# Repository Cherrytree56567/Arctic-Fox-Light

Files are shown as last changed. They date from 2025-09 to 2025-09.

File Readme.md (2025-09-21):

# Minecraft Arctic Fox Lamp
A simple Minecraft Themed Arctic Fox Lamp that features an ESP32 C6 Mini with ESP Matter Support which supports Temperature, Hue/Sat and Brightness.

## Features
 - Custom Color LED
 - Smart Home Integration
 - Matter Support
 - Enclosure

## Build
To Run the Matter ESP32 Program, install `ESP-IDF`:
```
git clone --recursive https://github.com/espressif/esp-idf.git
cd esp-idf
git submodule update --init --recursive
./install.sh
cd ../
```
Install `ESP-Matter`:
```
git clone https://github.com/espressif/esp-matter.git
cd esp-matter
git submodule update
cd connectedhomeip/connedtedhomeip/
git submodule update
cd ../../
```
Next source both repo's:
```
cd esp-idf
source ./export.sh
cd ../
cd esp-matter
source ./export.sh
cd ../
```

Then build the project by running
```
idf.py build
```

## Running
To run the application, run:
```
idf.py flash
```

## Credits
 - [Template ESP32 Matter Repo](https://github.com/oidebrett/starter-esp-matter-app)

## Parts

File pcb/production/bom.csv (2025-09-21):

Designator | Footprint | Quantity | Value | LCSC Part #
C1, C13 | 0805 | 2 | 10uF | C15850
C12 | 0805 | 1 | 100nF | C49678
D1 | LED_WS2812B_PLCC4_5.0x5.0mm_P3.2mm | 1 | WS2812B
J1 | USB_C_Receptacle_HCTL_HC-TYPE-C-16P-01A | 1 | USB_C_Receptacle_USB2.0_16P
R1, R2 | 0201 | 2 | R5.1K
R10, R8, R9 | 0201 | 3 | R10k
R3, R6 | 0201 | 2 | R27O
R7 | 0201 | 1 | R330o
U1 | TO-263-5_TabPin3 | 1 | LM2596S-5
U2 | ESP32-C6-MINI-1 | 1 | ESP32-C6-MINI-1/U
U3 | TO-263-5_TabPin3 | 1 | LM2596S-3.3
U4 | DIP794W45P254L1930H508Q14 | 1 | SN74AHCT125N

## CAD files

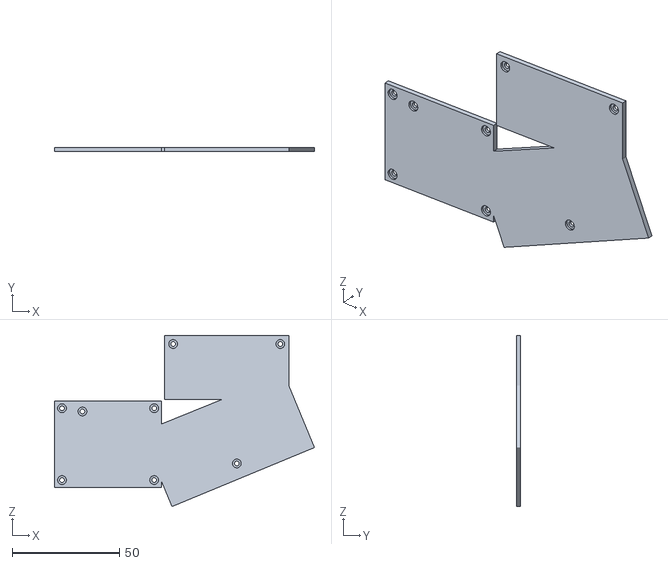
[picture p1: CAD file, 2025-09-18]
enclosure/Part Studio 1 - Part 1.stl
121.3 x 2.00 x 79.9

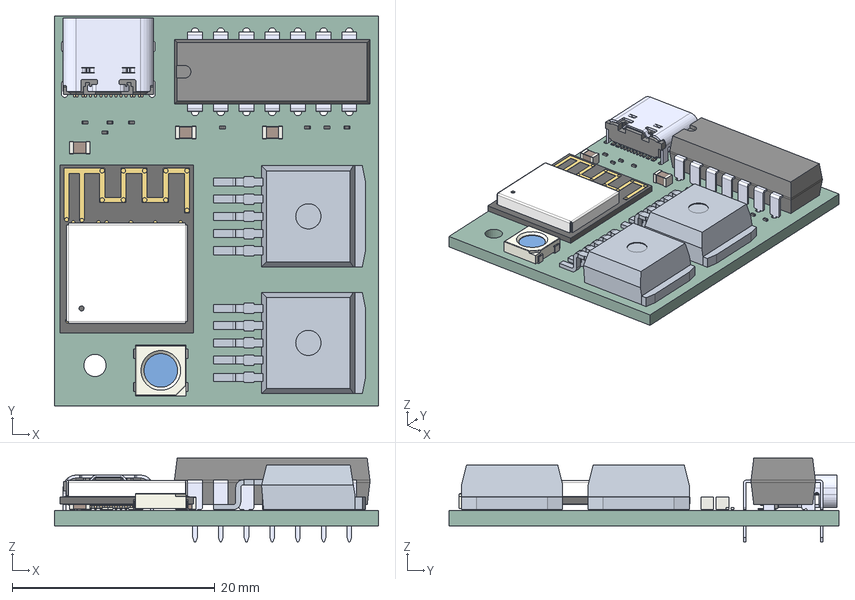
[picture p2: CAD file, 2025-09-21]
pcb/arcticfoxlight.step
32.0 x 38.5 x 8.26 mm
R_0201_0603Metric x 8
SN74AHCT125N
LED_WS2812B_PLCC4_5.0x5.0mm_P3.2mm
KH-TYPE-C-16P--3DModel-STEP-269445
DFN1006.STEP^DFN1006.STEP_Submodel-SOD882_part_DesignRootModel_PCB_ ESP32-C3-MINI-1_V1(2)_PCB_ESP32-C3-MINI-1_V1
R0201_20210301.STEP^R0201_20210301.STEP_Submodel-R0201_part_ DesignRootModel_PCB_ESP32-C3-MINI-1_V1(2)_PCB_ESP32-C3-MINI-1_V1 x 3
placementOutline^Submodel-noModelForPart_MINI-ANT-TYPED-H_1968823293_ Submodel-MINI-ANT-TYPED-H_1968823293_part_DesignRootModel_PCB_ ESP32-C3-MINI-1_V1(2)_PCB_E
placementOutline-0^Submodel-noModelForPart_MINI-ANT-TYPED-H_1968823293_ Submodel-MINI-ANT-TYPED-H_1968823293_part_DesignRootModel_PCB_ ESP32-C3-MINI-1_V1(2)_PCB
placementOutline-1^Submodel-noModelForPart_MINI-ANT-TYPED-H_1968823293_ Submodel-MINI-ANT-TYPED-H_1968823293_part_DesignRootModel_PCB_ ESP32-C3-MINI-1_V1(2)_PCB
placementOutline-2^Submodel-noModelForPart_MINI-ANT-TYPED-H_1968823293_ Submodel-MINI-ANT-TYPED-H_1968823293_part_DesignRootModel_PCB_ ESP32-C3-MINI-1_V1(2)_PCB
placementOutline-3^Submodel-noModelForPart_MINI-ANT-TYPED-H_1968823293_ Submodel-MINI-ANT-TYPED-H_1968823293_part_DesignRootModel_PCB_ ESP32-C3-MINI-1_V1(2)_PCB
placementOutline-4^Submodel-noModelForPart_MINI-ANT-TYPED-H_1968823293_ Submodel-MINI-ANT-TYPED-H_1968823293_part_DesignRootModel_PCB_ ESP32-C3-MINI-1_V1(2)_PCB
placementOutline-5^Submodel-noModelForPart_MINI-ANT-TYPED-H_1968823293_ Submodel-MINI-ANT-TYPED-H_1968823293_part_DesignRootModel_PCB_ ESP32-C3-MINI-1_V1(2)_PCB
trace_4^Submodel-MINI-ANT-TYPED-H_1968823293_part_DesignRootModel_PCB_ ESP32-C3-MINI-1_V1(2)_PCB_ESP32-C3-MINI-1_V1
trace_1^Submodel-MINI-ANT-TYPED-H_1968823293_part_DesignRootModel_PCB_ ESP32-C3-MINI-1_V1(2)_PCB_ESP32-C3-MINI-1_V1
C0402_20210301.STEP^C0402_20210301.STEP_Submodel-C0402_part_ DesignRootModel_PCB_ESP32-C3-MINI-1_V1(2)_PCB_ESP32-C3-MINI-1_V1
C0201_20210301.STEP^C0201_20210301.STEP_Submodel-C0201_part_ DesignRootModel_PCB_ESP32-C3-MINI-1_V1(2)_PCB_ESP32-C3-MINI-1_V1 x 11
L0201_20210301.STEP^L0201_20210301.STEP_Submodel-L0201_part_ DesignRootModel_PCB_ESP32-C3-MINI-1_V1(2)_PCB_ESP32-C3-MINI-1_V1 x 2
XTAL3225_20210301.STEP^XTAL3225_20210301.STEP_Submodel-XTAL3225_part_ DesignRootModel_PCB_ESP32-C3-MINI-1_V1(2)_PCB_ESP32-C3-MINI-1_V1
ESP32-C3_20210301.STEP^ESP32-C3_20210301.STEP_Submodel-QFN32_0P5_5_ part_DesignRootModel_PCB_ESP32-C3-MINI-1_V1(2)_PCB_ESP32-C3-MINI-1_V1
uid__4^DesignRootModel_PCB_ESP32-C3-MINI-1_V1(2)_PCB_ESP32-C3-MINI-1_ V1
uid__4-22^DesignRootModel_PCB_ESP32-C3-MINI-1_V1(2)_PCB_ ESP32-C3-MINI-1_V1
uid__4-23^DesignRootModel_PCB_ESP32-C3-MINI-1_V1(2)_PCB_ ESP32-C3-MINI-1_V1
uid__4-24^DesignRootModel_PCB_ESP32-C3-MINI-1_V1(2)_PCB_ ESP32-C3-MINI-1_V1
uid__4-25^DesignRootModel_PCB_ESP32-C3-MINI-1_V1(2)_PCB_ ESP32-C3-MINI-1_V1
uid__4-26^DesignRootModel_PCB_ESP32-C3-MINI-1_V1(2)_PCB_ ESP32-C3-MINI-1_V1
uid__4-27^DesignRootModel_PCB_ESP32-C3-MINI-1_V1(2)_PCB_ ESP32-C3-MINI-1_V1
uid__4-28^DesignRootModel_PCB_ESP32-C3-MINI-1_V1(2)_PCB_ ESP32-C3-MINI-1_V1
uid__4-29^DesignRootModel_PCB_ESP32-C3-MINI-1_V1(2)_PCB_ ESP32-C3-MINI-1_V1
uid__4-30^DesignRootModel_PCB_ESP32-C3-MINI-1_V1(2)_PCB_ ESP32-C3-MINI-1_V1
uid__4-31^DesignRootModel_PCB_ESP32-C3-MINI-1_V1(2)_PCB_ ESP32-C3-MINI-1_V1
uid__4-32^DesignRootModel_PCB_ESP32-C3-MINI-1_V1(2)_PCB_ ESP32-C3-MINI-1_V1
uid__4-33^DesignRootModel_PCB_ESP32-C3-MINI-1_V1(2)_PCB_ ESP32-C3-MINI-1_V1
uid__4-34^DesignRootModel_PCB_ESP32-C3-MINI-1_V1(2)_PCB_ ESP32-C3-MINI-1_V1
uid__4-35^DesignRootModel_PCB_ESP32-C3-MINI-1_V1(2)_PCB_ ESP32-C3-MINI-1_V1
uid__4-36^DesignRootModel_PCB_ESP32-C3-MINI-1_V1(2)_PCB_ ESP32-C3-MINI-1_V1
uid__4-37^DesignRootModel_PCB_ESP32-C3-MINI-1_V1(2)_PCB_ ESP32-C3-MINI-1_V1
uid__4-38^DesignRootModel_PCB_ESP32-C3-MINI-1_V1(2)_PCB_ ESP32-C3-MINI-1_V1
uid__4-39^DesignRootModel_PCB_ESP32-C3-MINI-1_V1(2)_PCB_ ESP32-C3-MINI-1_V1
uid__4-40^DesignRootModel_PCB_ESP32-C3-MINI-1_V1(2)_PCB_ ESP32-C3-MINI-1_V1
uid__4-41^DesignRootModel_PCB_ESP32-C3-MINI-1_V1(2)_PCB_ ESP32-C3-MINI-1_V1
uid__4-42^DesignRootModel_PCB_ESP32-C3-MINI-1_V1(2)_PCB_ ESP32-C3-MINI-1_V1
uid__4-43^DesignRootModel_PCB_ESP32-C3-MINI-1_V1(2)_PCB_ ESP32-C3-MINI-1_V1
uid__4-44^DesignRootModel_PCB_ESP32-C3-MINI-1_V1(2)_PCB_ ESP32-C3-MINI-1_V1
uid__4-45^DesignRootModel_PCB_ESP32-C3-MINI-1_V1(2)_PCB_ ESP32-C3-MINI-1_V1
uid__4-46^DesignRootModel_PCB_ESP32-C3-MINI-1_V1(2)_PCB_ ESP32-C3-MINI-1_V1
uid__4-47^DesignRootModel_PCB_ESP32-C3-MINI-1_V1(2)_PCB_ ESP32-C3-MINI-1_V1
uid__4-48^DesignRootModel_PCB_ESP32-C3-MINI-1_V1(2)_PCB_ ESP32-C3-MINI-1_V1
uid__4-49^DesignRootModel_PCB_ESP32-C3-MINI-1_V1(2)_PCB_ ESP32-C3-MINI-1_V1
uid__4-50^DesignRootModel_PCB_ESP32-C3-MINI-1_V1(2)_PCB_ ESP32-C3-MINI-1_V1
uid__4-51^DesignRootModel_PCB_ESP32-C3-MINI-1_V1(2)_PCB_ ESP32-C3-MINI-1_V1
uid__4-52^DesignRootModel_PCB_ESP32-C3-MINI-1_V1(2)_PCB_ ESP32-C3-MINI-1_V1
uid__4-53^DesignRootModel_PCB_ESP32-C3-MINI-1_V1(2)_PCB_ ESP32-C3-MINI-1_V1
uid__4-54^DesignRootModel_PCB_ESP32-C3-MINI-1_V1(2)_PCB_ ESP32-C3-MINI-1_V1
uid__4-55^DesignRootModel_PCB_ESP32-C3-MINI-1_V1(2)_PCB_ ESP32-C3-MINI-1_V1
uid__4-56^DesignRootModel_PCB_ESP32-C3-MINI-1_V1(2)_PCB_ ESP32-C3-MINI-1_V1
uid__4-57^DesignRootModel_PCB_ESP32-C3-MINI-1_V1(2)_PCB_ ESP32-C3-MINI-1_V1
uid__4-58^DesignRootModel_PCB_ESP32-C3-MINI-1_V1(2)_PCB_ ESP32-C3-MINI-1_V1
uid__4-59^DesignRootModel_PCB_ESP32-C3-MINI-1_V1(2)_PCB_ ESP32-C3-MINI-1_V1
uid__4-60^DesignRootModel_PCB_ESP32-C3-MINI-1_V1(2)_PCB_ ESP32-C3-MINI-1_V1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

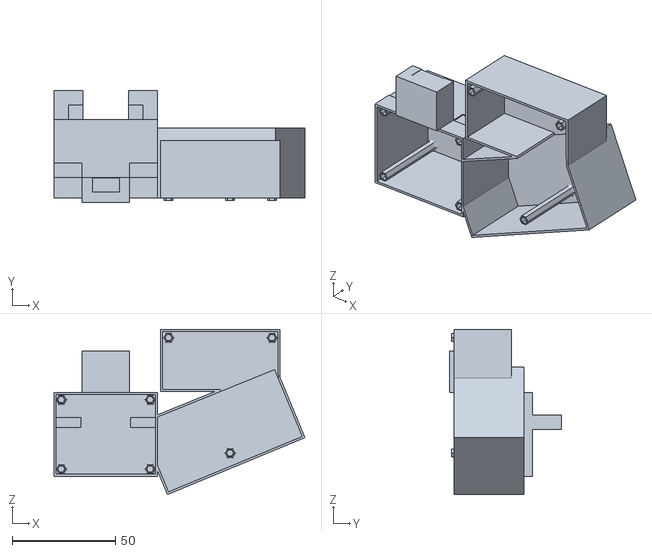
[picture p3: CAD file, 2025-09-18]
enclosure/Part Studio 1 - Part 2.stl
121.3 x 54.0 x 79.9

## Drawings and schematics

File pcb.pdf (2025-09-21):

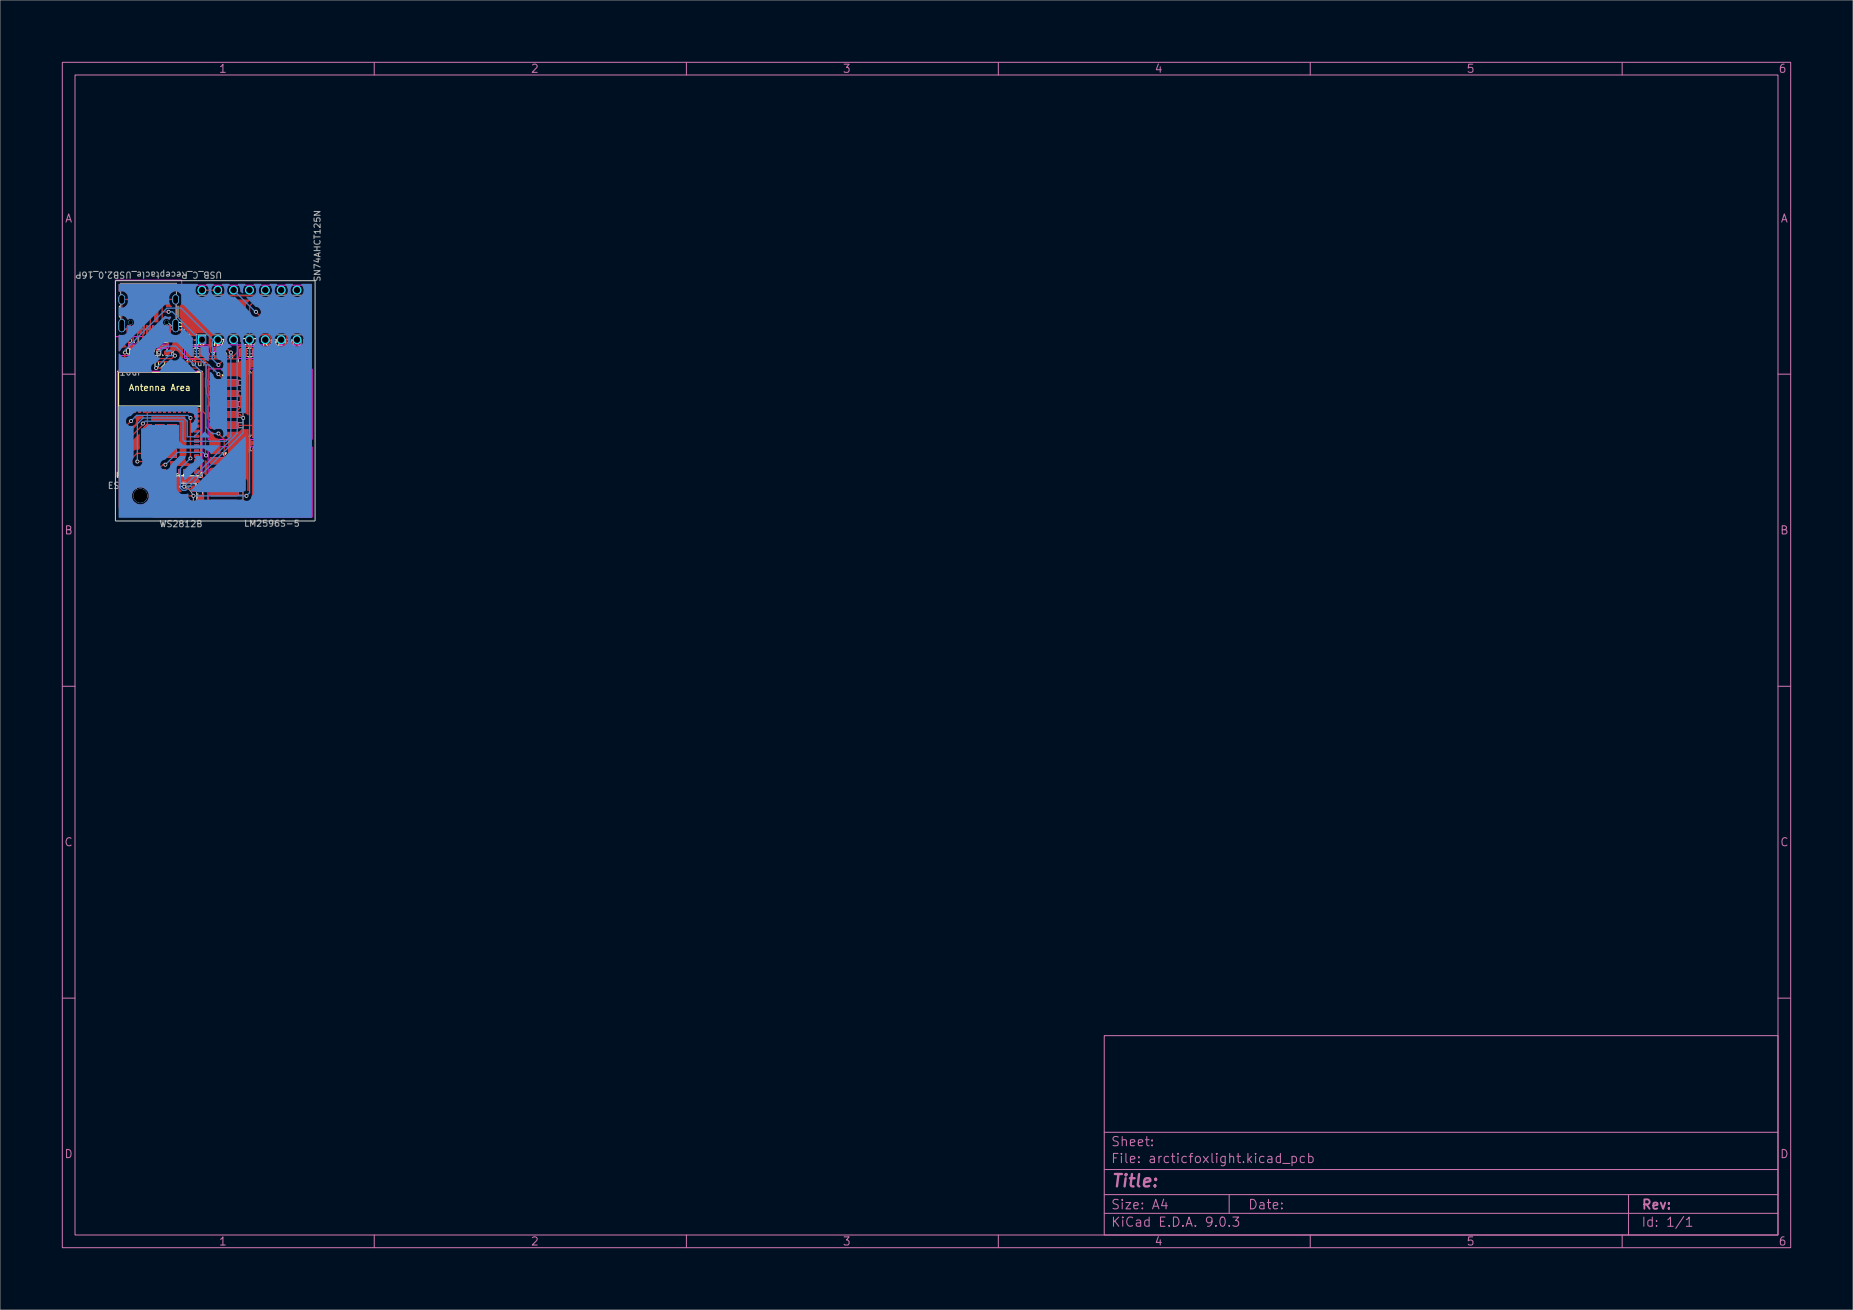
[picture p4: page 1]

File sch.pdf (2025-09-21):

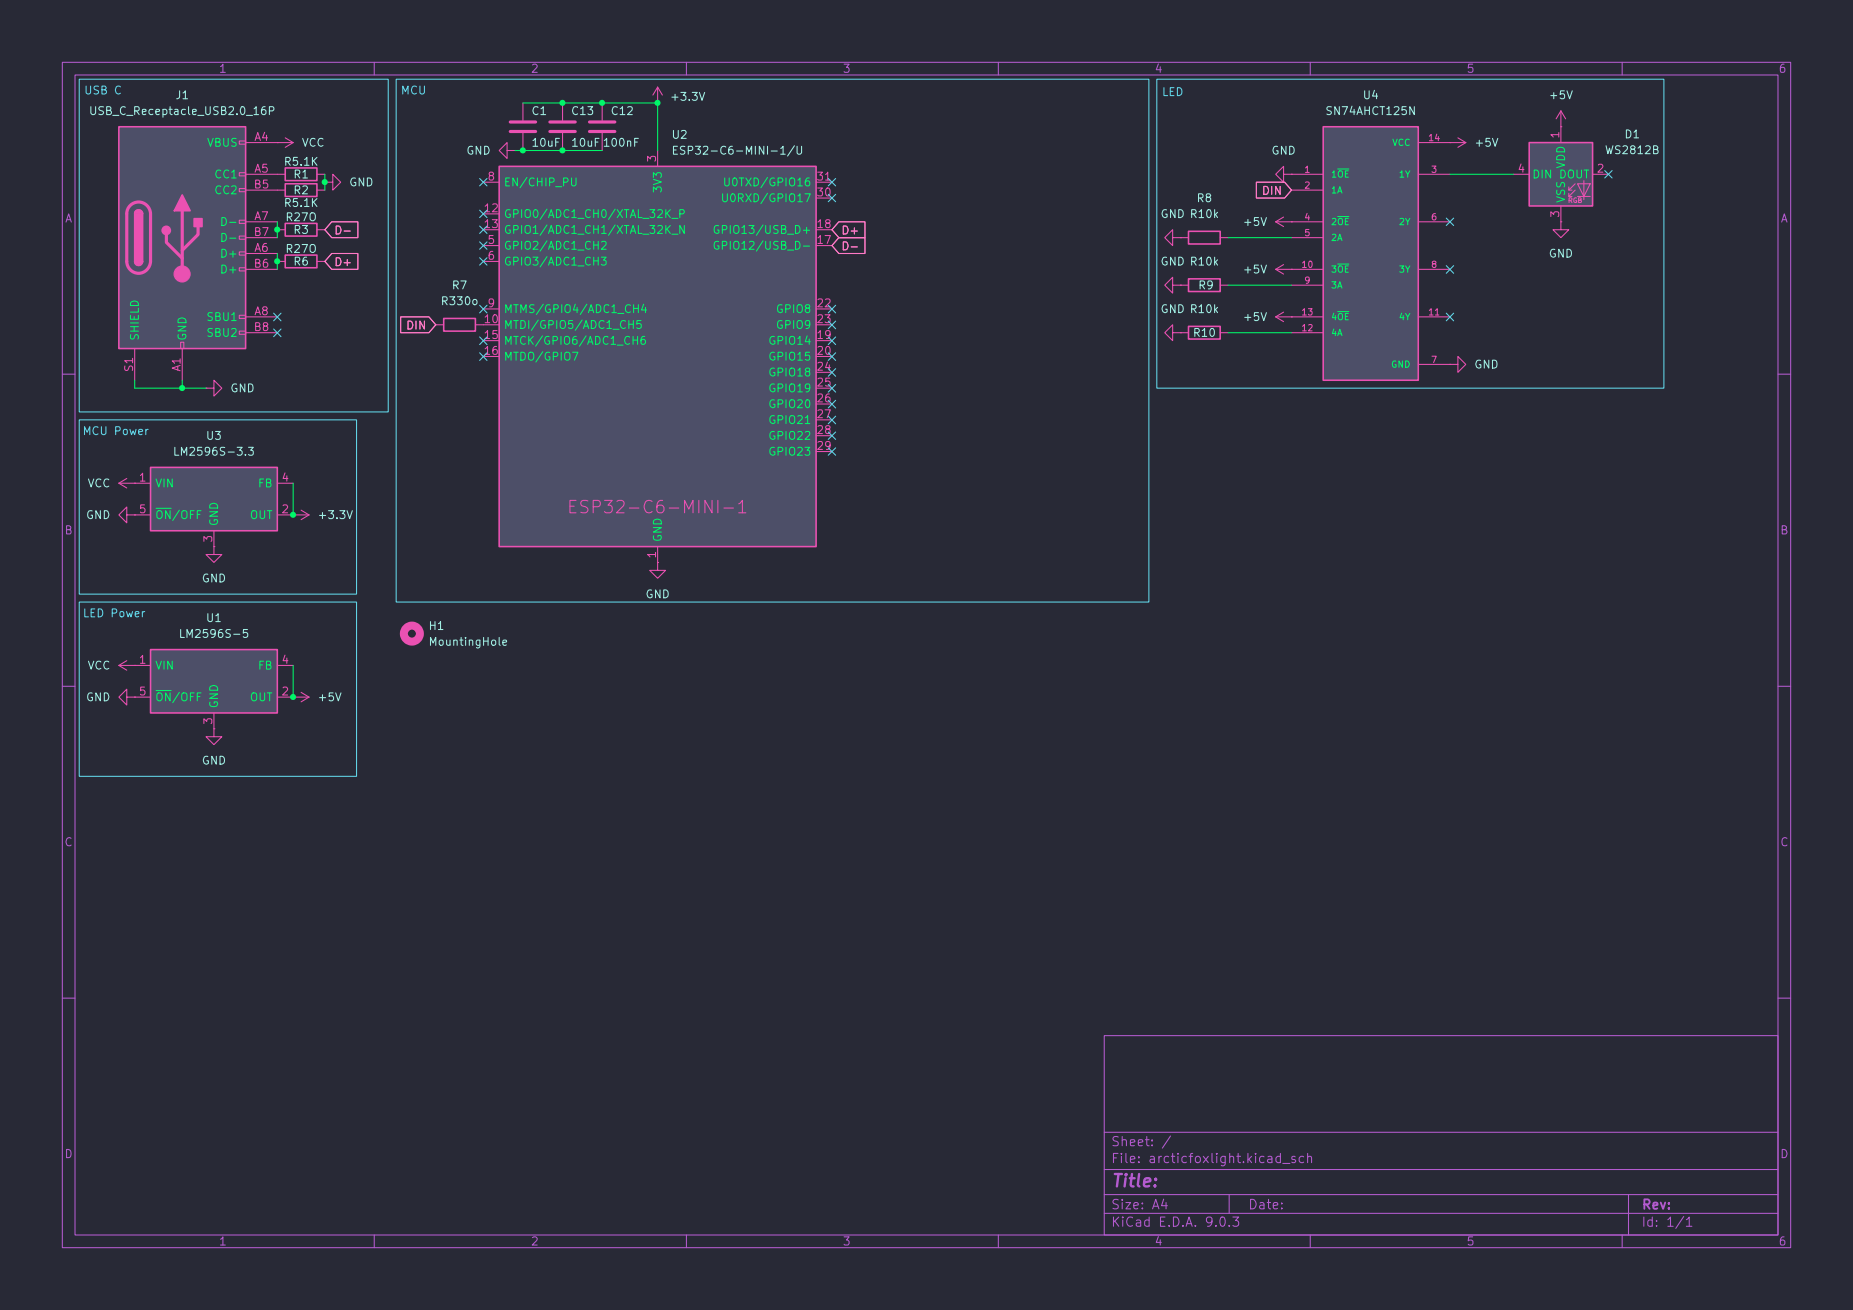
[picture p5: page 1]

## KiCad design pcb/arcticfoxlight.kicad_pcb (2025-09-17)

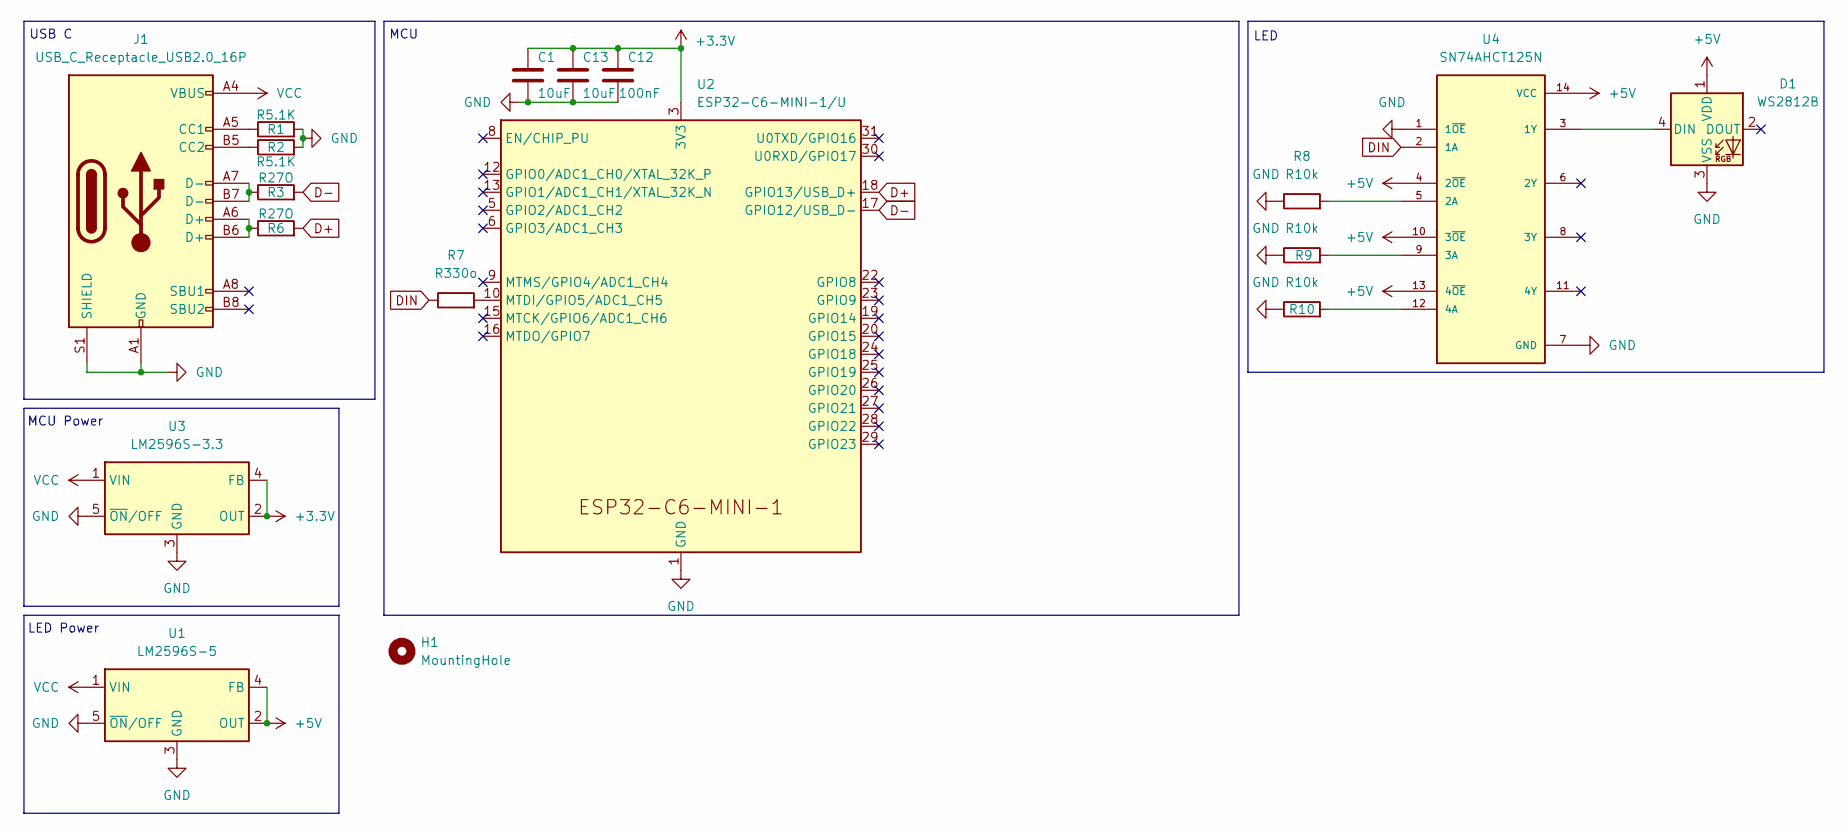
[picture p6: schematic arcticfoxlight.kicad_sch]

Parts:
C1, C13: 10uF; C_0805_2012Metric_Pad1.18x1.45mm_HandSolder; LCSC C15850
C12: 100nF; C_0805_2012Metric_Pad1.18x1.45mm_HandSolder; LCSC C49678
D1: WS2812B; LED_WS2812B_PLCC4_5.0x5.0mm_P3.2mm
H1: MountingHole; MountingHole_2.2mm_M2
J1: USB_C_Receptacle_USB2.0_16P; USB_C_Receptacle_HCTL_HC-TYPE-C-16P-01A
R1, R2: R5.1K; R_0201_0603Metric_Pad0.64x0.40mm_HandSolder
R3, R6: R27O; R_0201_0603Metric_Pad0.64x0.40mm_HandSolder
R7: R330o; R_0201_0603Metric_Pad0.64x0.40mm_HandSolder
R8, R9, R10: R10k; R_0201_0603Metric_Pad0.64x0.40mm_HandSolder
U1: LM2596S-5; TO-263-5_TabPin3
U2: ESP32-C6-MINI-1/U; ESP32-C6-MINI-1
U3: LM2596S-3.3; TO-263-5_TabPin3
U4: SN74AHCT125N; DIP794W45P254L1930H508Q14; PARTREV Q

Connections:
+3.3V: C1.1, C12.1, C13.1, U2.3 (3V3), U3.2 (OUT), U3.4 (FB)
+5V: D1.1 (VDD), U1.2 (OUT), U1.4 (FB), U4.4 (2~OE), U4.10 (3~OE), U4.13 (4~OE), U4.14 (VCC)
D+: R6.2, U2.18 (GPIO13/USB_D+)
D-: R3.2, U2.17 (GPIO12/USB_D-)
DIN: R7.1, U4.2 (1A)
GND: C1.2, C12.2, C13.2, D1.3 (VSS), J1.A1 (GND), J1.A12 (GND), J1.B1 (GND), J1.B12 (GND), J1.S1 (SHIELD), R1.2, R2.2, R8.1, R9.1, R10.1, U1.3 (GND), U1.5 (~ON/OFF), U2.1 (GND), U2.2 (GND), U2.11 (GND), U2.14 (GND), U2.36 (GND), U2.37 (GND), U2.38 (GND), U2.39 (GND), U2.40 (GND), U2.41 (GND), U2.42 (GND), U2.43 (GND), U2.44 (GND), U2.45 (GND), U2.46 (GND), U2.47 (GND), U2.48 (GND), U2.49 (GND), U2.50 (GND), U2.51 (GND), U2.52 (GND), U2.53 (GND), U3.3 (GND), U3.5 (~ON/OFF), U4.1 (1~OE), U4.7 (GND)
unnamed: D1.4 (DIN), U4.3 (1Y)
unnamed: J1.A5 (CC1), R1.1
unnamed: J1.B5 (CC2), R2.1
unnamed: J1.A6 (D+), J1.B6 (D+), R6.1
unnamed: J1.A7 (D-), J1.B7 (D-), R3.1
unnamed: R7.2, U2.10 (MTDI/GPIO5/ADC1_CH5)
unnamed: R8.2, U4.5 (2A)
unnamed: R9.2, U4.9 (3A)
unnamed: R10.2, U4.12 (4A)
VCC: J1.A4 (VBUS), J1.A9 (VBUS), J1.B4 (VBUS), J1.B9 (VBUS), U1.1 (VIN), U3.1 (VIN)

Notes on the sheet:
LED
USB C
MCU Power
LED Power
MCU

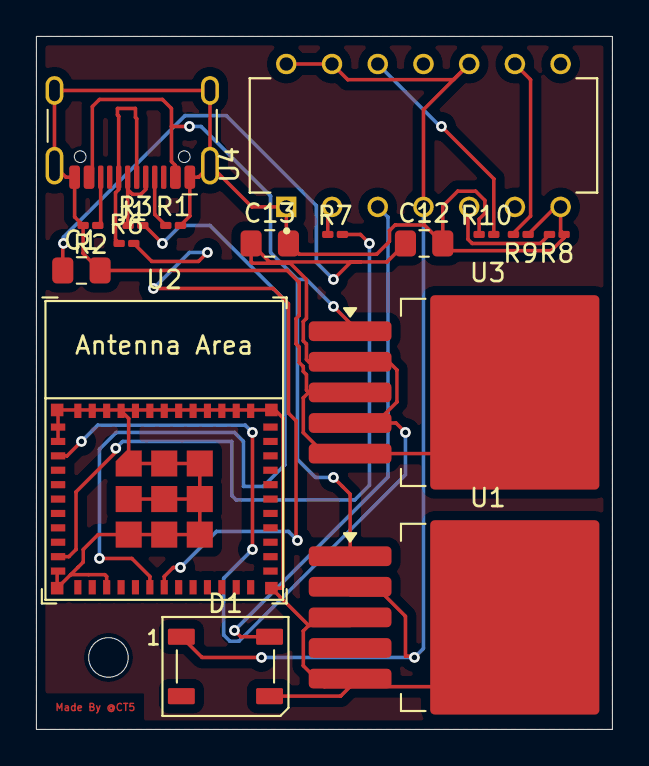
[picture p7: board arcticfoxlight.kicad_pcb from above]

Board: 2 copper layers, 32.0 x 38.5 mm, 18 parts (0 on the bottom side), 16 nets.

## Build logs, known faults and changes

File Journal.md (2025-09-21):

---
Title: "Arctic Fox Lamp"
Author: "CT5"
Description: "A simple lamp with a custom enclosure and pcb which allows users to change the color of the led via Smart Home Devices."
Created On: "15/09/2025"
---

# September 16th: Found an LED and started the PCB!

Finding a good LED for my project was pretty hard. I needed an LED that I could integrate in KiCad and change the color of. Aliexpress was my first option where I was able to find this [RGB WS2812B 5V 5050 LED](https://www.aliexpress.com/item/1005009855473477.html) for pretty cheap. Then I needed a microcontroller that would support Bluetooth and WiFi for the Smart Home Integration. I was able to find the ESP32-C6-MINI-1 on [Espressif's ESP Selector](https://products.espressif.com/#/product-selector) Website. The pcb itself is pretty messy, but Ill get that sorted tomorrow.

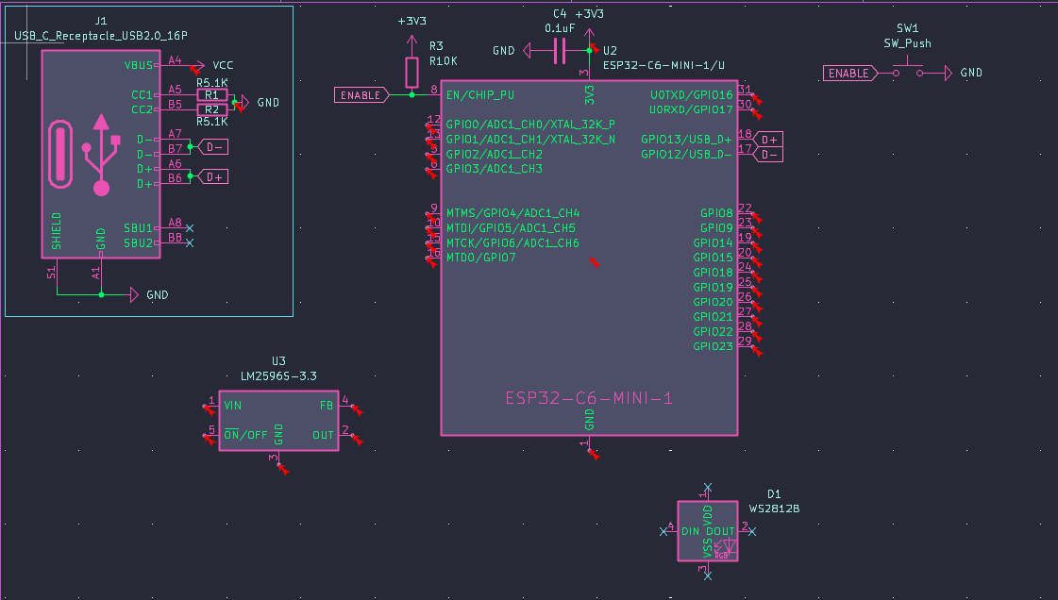
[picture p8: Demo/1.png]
Demo 1


**Total time spent: 1h 40m 41s**

# September 17th: Wiring Is Hard!

Wiring up the MCU and the LEDs and stuff is really hard. Looking at diagrams and datasheets is even worser. Most of the datasheets didn't really show me what to wire up and where, so I had to look online, but there wasn't any info online. So I had to do my best, by reading the datasheet and connecting things. I wasn't really sure if what I had connected was 100% correct, but hopefully im lucky and I don't mess up somewhere. At least wiring up the PCB was easier.

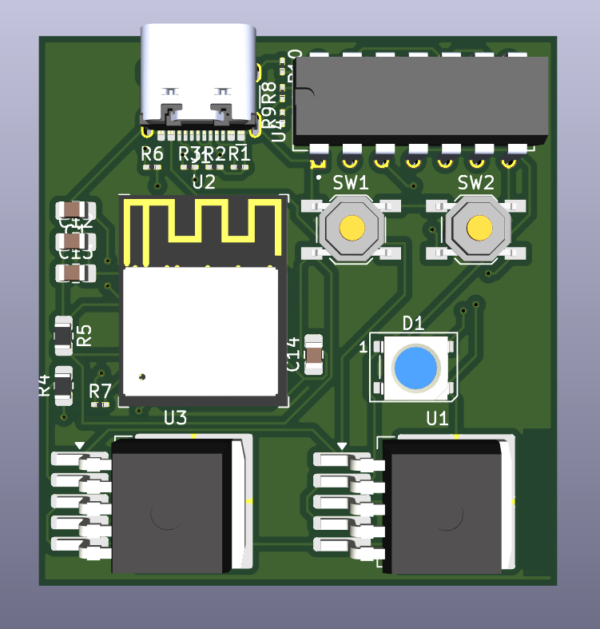
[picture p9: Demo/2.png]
Demo 2


**Total time spent: 1h 19m 57s**

# September 17th: 3D Modelling!

Making the Arctic Fox was pretty hard because I have never tried to make minecraft characters before. Ive made enclosures so that part was a breeze. I was able to finish the fox head. Oh, by the way, this project is a part of my school's art project where we 3D Print a Minecraft Character and Paint it. I decided to turn it into a lamp, so I needed to use thin layers of white PLA. Ive used 1mm, but 0.5mm could give a greater result. Ill report back once its printed.

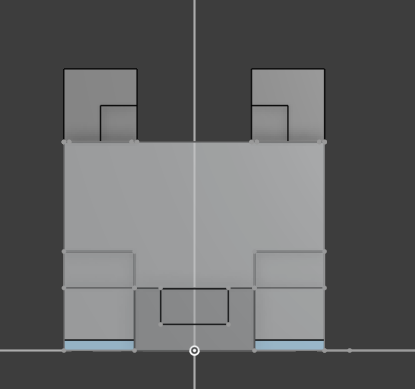
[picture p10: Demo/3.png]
Demo 3


**Total time spent: 2h 10m 25s**

# September 18th: Arctic Fox Modelling!

3D Modelling the Arctic Fox was hard, but I was able to do it. Unfortunatly, I forgot to add the USB C Port Cutout before submitting it, so I can't change it again. I used M2 Screws and M2x3mm Threads since I already have those. I took inspiration from this [Sleeping Arctic Fox](https://www.printables.com/model/403207-sleeping-arctic-fox-minecraft) 3D Model from Printables, because it looked fairly accurate.

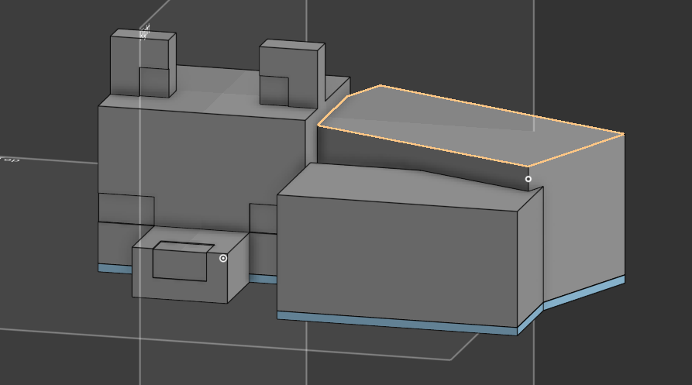
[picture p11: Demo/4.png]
Demo 4


**Total time spent: 58m 48s**

# September 19th: Arctic Fox Matter Code!

I was looking online for a way to get the ESP32 to support Matter, and I found out that there was ESP-IDF and ESP-Matter. To use these repo's though, it took me 2 days to clone. After that, I was able to use the [ESP Matter Tutorial](https://mattercoder.com/codelabs/how-to-code-a-matter-app-on-esp32/#2), which guided me through a simple LED Example. I was then able to modify it to add more features, like a permenant pin and a temperature, brightness, hue/sat. Unfortunatly, I don't have the ESP32 to test it out so here is a quick screenshot of my code.

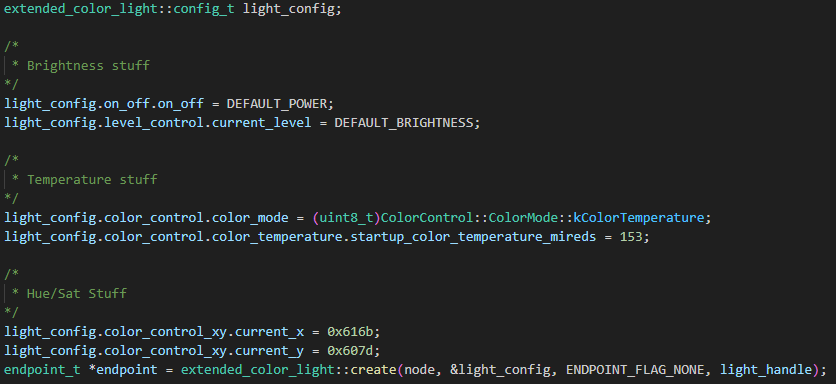
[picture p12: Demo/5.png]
Demo 5


**Total time spent: 1h 57m**

# Final Submission
**Total time: 8h 4m**

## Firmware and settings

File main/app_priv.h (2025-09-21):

/*
   This example code is in the Public Domain (or CC0 licensed, at your option.)

   Unless required by applicable law or agreed to in writing, this
   software is distributed on an "AS IS" BASIS, WITHOUT WARRANTIES OR
   CONDITIONS OF ANY KIND, either express or implied.
*/

#pragma once

#include <esp_err.h>
#include <esp_matter.h>

#include <driver/gpio.h>
#define LED        ((gpio_num_t) 5)

#if CHIP_DEVICE_CONFIG_ENABLE_THREAD
#include "esp_openthread_types.h"
#endif

/** Standard max values (used for remapping attributes) */
#define STANDARD_BRIGHTNESS 100
#define STANDARD_HUE 360
#define STANDARD_SATURATION 100
#define STANDARD_TEMPERATURE_FACTOR 1000000

/** Matter max values (used for remapping attributes) */
#define MATTER_BRIGHTNESS 254
#define MATTER_HUE 254
#define MATTER_SATURATION 254
#define MATTER_TEMPERATURE_FACTOR 1000000

/** Default attribute values used during initialization */
#define DEFAULT_POWER true
#define DEFAULT_BRIGHTNESS 64
#define DEFAULT_HUE 128
#define DEFAULT_SATURATION 254

typedef void *app_driver_handle_t;

/** Initialize the light driver
 *
 * This initializes the light driver associated with the selected board.
 *
 * @return Handle on success.
 * @return NULL in case of failure.
 */
app_driver_handle_t app_driver_light_init();

/** Driver Update
 *
 * This API should be called to update the driver for the attribute being updated.
 * This is usually called from the common `app_attribute_update_cb()`.
 *
 * @param[in] endpoint_id Endpoint ID of the attribute.
 * @param[in] cluster_id Cluster ID of the attribute.
 * @param[in] attribute_id Attribute ID of the attribute.
 * @param[in] val Pointer to `esp_matter_attr_val_t`. Use appropriate elements as per the value type.
 *
 * @return ESP_OK on success.
 * @return error in case of failure.
 */
esp_err_t app_driver_attribute_update(app_driver_handle_t driver_handle, uint16_t endpoint_id, uint32_t cluster_id,
                                      uint32_t attribute_id, esp_matter_attr_val_t *val);

/** Set defaults for light driver
 *
 * Set the attribute drivers to their default values from the created data model.
 *
 * @param[in] endpoint_id Endpoint ID of the driver.
 *
 * @return ESP_OK on success.
 * @return error in case of failure.
 */
esp_err_t app_driver_light_set_defaults(uint16_t endpoint_id);

#if CHIP_DEVICE_CONFIG_ENABLE_THREAD
#define ESP_OPENTHREAD_DEFAULT_RADIO_CONFIG()                                           \
    {                                                                                   \
        .radio_mode = RADIO_MODE_NATIVE,                                                \
    }

#define ESP_OPENTHREAD_DEFAULT_HOST_CONFIG()                                            \
    {                                                                                   \
        .host_connection_mode = HOST_CONNECTION_MODE_NONE,                              \
    }

#define ESP_OPENTHREAD_DEFAULT_PORT_CONFIG()                                            \
    {                                                                                   \
        .storage_partition_name = "nvs", .netif_queue_size = 10, .task_queue_size = 10, \
    }
#endif

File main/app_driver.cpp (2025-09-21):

#include <esp_log.h>
#include <stdlib.h>
#include <string.h>

#include <device.h>
#include <esp_matter.h>
#include <led_driver.h>

#include <app_priv.h>

using namespace chip::app::Clusters;
using namespace esp_matter;

static const char *TAG = "app_driver";
extern uint16_t light_endpoint_id;
static led_driver_handle_t handle;

/*
 * Translation Functions
*/
int map_brightness(uint8_t matter_val) {
    return (matter_val * 100) / MATTER_BRIGHTNESS;
}

int map_hue(uint8_t matter_val) {
    return (matter_val * 360) / MATTER_HUE;
}

int map_saturation(uint8_t matter_val) {
    return (matter_val * 100) / MATTER_SATURATION;
}

int mired_to_kelvin(uint16_t mireds) {
    return MATTER_TEMPERATURE_FACTOR / mireds;
}

static esp_err_t app_driver_light_set_brightness(esp_matter_attr_val_t *val) {
    int pwm_val = map_brightness(val->val.u8);
    led_driver_set_brightness(handle, pwm_val);
    return ESP_OK;
}

static esp_err_t app_driver_light_set_color_temp(esp_matter_attr_val_t *val) {
    int kelvin = mired_to_kelvin(val->val.u16);
    led_driver_set_temperature(handle, kelvin);
    return ESP_OK;
}

static esp_err_t app_driver_light_set_hue(esp_matter_attr_val_t *val) {
    int hue_deg = map_hue(val->val.u8);
    led_driver_set_hue(handle, hue_deg);
    return ESP_OK;
}

static esp_err_t app_driver_light_set_saturation(esp_matter_attr_val_t *val) {
    int sat = map_saturation(val->val.u8);
    led_driver_set_saturation(handle, sat);

    return ESP_OK;
}

static esp_err_t app_driver_light_set_on_off(esp_matter_attr_val_t *val) {
    ESP_LOGI(TAG, "Changing the GPIO LED!");

    led_driver_set_power(handle, val->val.b);

    return ESP_OK;
}

esp_err_t app_driver_attribute_update(app_driver_handle_t driver_handle, uint16_t endpoint_id, uint32_t cluster_id, uint32_t attribute_id, esp_matter_attr_val_t *val) {
    esp_err_t err = ESP_OK;

    if (endpoint_id == light_endpoint_id) {
        if (cluster_id == OnOff::Id && attribute_id == OnOff::Attributes::OnOff::Id) {
            err = app_driver_light_set_on_off(val);
        } 
        else if (cluster_id == LevelControl::Id && attribute_id == LevelControl::Attributes::CurrentLevel::Id) {
            err = app_driver_light_set_brightness(val);
        }
        else if (cluster_id == ColorControl::Id) {
            if (attribute_id == ColorControl::Attributes::CurrentHue::Id) {
                err = app_driver_light_set_hue(val);
            } else if (attribute_id == ColorControl::Attributes::CurrentSaturation::Id) {
                err = app_driver_light_set_saturation(val);
            } else if (attribute_id == ColorControl::Attributes::ColorTemperatureMireds::Id) {
                err = app_driver_light_set_color_temp(val);
            }
        }
    }

    return err;
}

app_driver_handle_t app_driver_light_init() {
    led_driver_config_t config = led_driver_get_config();

    config.gpio = 5;

    handle = led_driver_init(&config);

    return (app_driver_handle_t)handle;
}

esp_err_t app_driver_light_set_defaults(uint16_t endpoint_id) {
    esp_err_t err = ESP_OK;
    node_t *node = node::get();
    endpoint_t *endpoint = endpoint::get(node, endpoint_id);
    cluster_t *cluster = NULL;
    attribute_t *attribute = NULL;
    esp_matter_attr_val_t val = esp_matter_invalid(NULL);

    // Set On/Off
    cluster = cluster::get(endpoint, OnOff::Id);
    attribute = attribute::get(cluster, OnOff::Attributes::OnOff::Id);
    attribute::get_val(attribute, &val);
    err |= app_driver_light_set_on_off(&val);

    // Set Brightness
    cluster = cluster::get(endpoint, LevelControl::Id);
    attribute = attribute::get(cluster, LevelControl::Attributes::CurrentLevel::Id);
    attribute::get_val(attribute, &val);
    err |= app_driver_light_set_brightness(&val);

    cluster = cluster::get(endpoint, ColorControl::Id);
    attribute = attribute::get(cluster, ColorControl::Attributes::CurrentHue::Id);
    attribute::get_val(attribute, &val);
    err |= app_driver_light_set_hue(&val);

    attribute = attribute::get(cluster, ColorControl::Attributes::CurrentSaturation::Id);
    attribute::get_val(attribute, &val);
    err |= app_driver_light_set_saturation(&val);

    attribute = attribute::get(cluster, ColorControl::Attributes::ColorTemperatureMireds::Id);
    attribute::get_val(attribute, &val);
    err |= app_driver_light_set_color_temp(&val);

    return err;
}

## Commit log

2025-09-17 Day 2
    [arcticfoxlight.kicad_pcb, arcticfoxlight.kicad_sch]
2025-09-17 Day 2.1
    [arcticfoxlight.kicad_pcb, arcticfoxlight.kicad_sch]
2025-09-18 Day 4
    [Part Studio 1 - Part 1.stl, Part Studio 1 - Part 2.stl]
